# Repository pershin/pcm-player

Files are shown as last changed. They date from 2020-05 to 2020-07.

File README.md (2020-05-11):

# PCM Player

Pulse-width modulation (PWM) audio player on ATmega328P-PU

## Requirements

### SD card

SDHC 2-32GB must be formatted to FAT32

### Audio files

Property          | Value
------------------|----------------------------
| Format:         | Unsigned 8-bit PCM (RAW)  |
| Sample rate:    | 44100 Hz                  |
| Channels:       | 2                         |
| File extension: | *.PCM                     |

#### Convert FLAC to PCM with FFmpeg

```bash
ffmpeg -i 'example.flac' -ar 44100 -acodec pcm_u8 -f u8 -ac 2 'EXAMPLE.PCM'
```

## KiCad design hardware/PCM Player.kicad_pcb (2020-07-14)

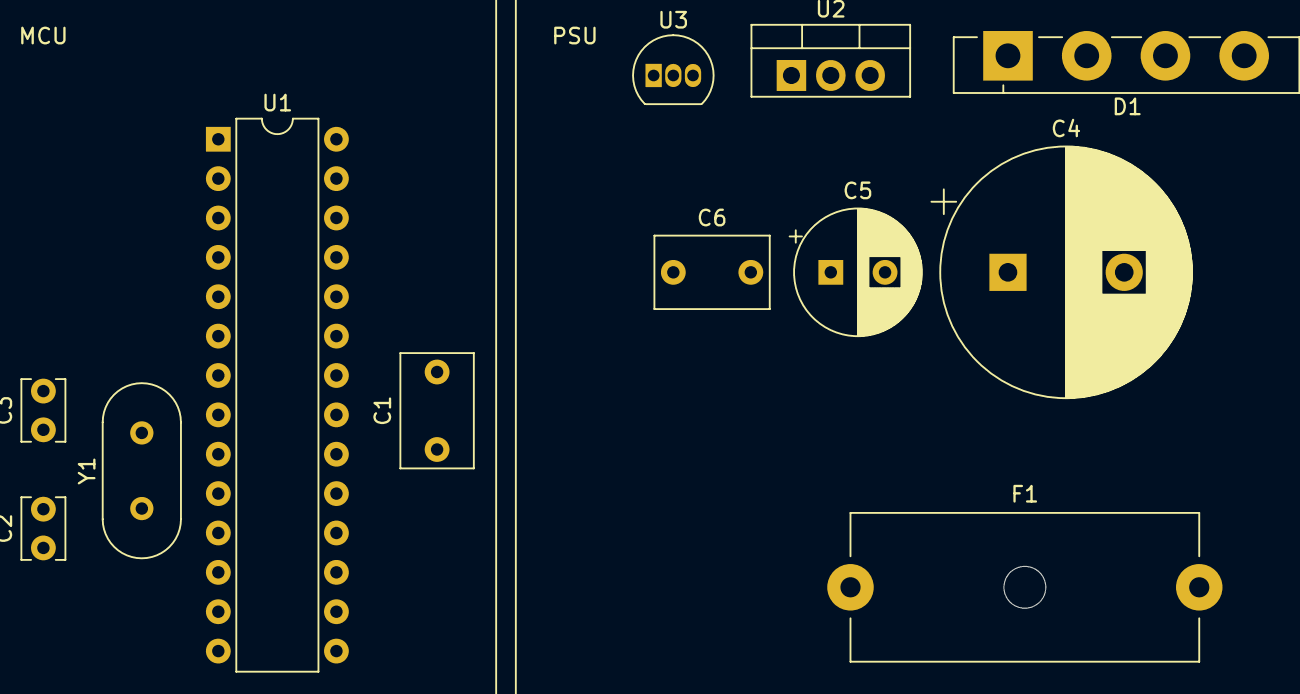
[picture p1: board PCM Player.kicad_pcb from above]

Board: 2 copper layers, 16 parts (0 on the bottom side), 6 nets, no tracks yet.

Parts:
C1, C6: 1u; C_Rect_L7.2mm_W4.5mm_P5.00mm_FKS2_FKP2_MKS2_MKP2
C2, C3: 22p; C_Disc_D3.8mm_W2.6mm_P2.50mm
C4: 4700u; CP_Radial_D16.0mm_P7.50mm
C5: 100u; CP_Radial_D8.0mm_P3.50mm
D1: GBU808; Diode_Bridge_Vishay_GBU
F1: 250V 4A; Fuseholder_Cylinder-5x20mm_Schurter_0031_8201_Horizontal_Op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
H1, H2, H3, H4: MountingHole; MountingHole_3.2mm_M3
U1: ATmega328P-PU; DIP-28_W7.62mm
U2: LM1085-5.0; TO-220-3_Vertical
U3: LP2950-3.3_TO92; TO-92_Inline
Y1: 16MHz; Crystal_HC49-U_Vertical

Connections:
+3V3: C6.1, U3.1
+5V: C1.1, C5.1, U1.7, U1.20, U2.2, U3.3
GND: C1.2, C2.2, C3.2, C4.2, C5.2, C6.2, D1.4, U1.8, U1.22, U2.1, U3.2
unnamed: C2.1, U1.10, Y1.1
unnamed: C3.1, U1.9, Y1.2
VCC: C4.1, D1.1, U2.3

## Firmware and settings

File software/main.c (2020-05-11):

/*
 * File:   main.c
 * Author: Sergey Pershin <sergey.pershin at hotmail.com>
 *
 * Created on May 7, 2020, 7:14 PM
 */

#include <avr/io.h>
#include <avr/interrupt.h>
#include <stdint.h>
#include "player.h"
#include "pins.h"
#include "spi.h"
#include "sd.h"
#include "fat32.h"
#include "display.h"

extern uint8_t command_id;
uint16_t current_track;
volatile uint8_t minutes;
volatile uint8_t seconds;
volatile uint16_t buffer_position;
volatile uint16_t position_count;
uint8_t buffer[BUFFER_SIZE];
uint8_t buffer_n;

ISR(TIMER1_COMPA_vect) {
  OCR2B = buffer[buffer_position++]; /* Left channel */
  OCR0B = buffer[buffer_position++]; /* Right channel */

  if (BUFFER_SIZE == buffer_position) {
    buffer_position = 0;
  }

  position_count--;

  if (0 == position_count) {
    position_count = SAMPLE_RATE;
    seconds++;

    /* Fix BCD */
    if (9 < (seconds & ~0b11110000)) {
      seconds += 0b00000110;
    }
  }

  if (0x60 == seconds) { /* 60 */
    seconds = 0;
    minutes++;

    /* Fix BCD */
    if (9 < (minutes & ~0b11110000)) {
      minutes += 0b00000110;
    }
  }
}

void next(void);

void read_to_buffer(void) {
  int16_t offset, read_result;

  if (0 == TIMSK1) {
    return;
  }

  if (0 == buffer_n) {
    if (BUFFER_CHUNK > buffer_position) {
      return;
    }

    buffer_n = 1;
    offset = 0;
  } else {
    if (BUFFER_CHUNK <= buffer_position) {
      return;
    }

    buffer_n = 0;
    offset = BUFFER_CHUNK;
  }

  read_result = file_read(&buffer[offset]);

  if (-1 == read_result) {
    next();
    return;
  }

  if (BUFFER_CHUNK > read_result) {
    next();
  }
}

void play(void) {
  /* Start timer (TIMER1_COMPA_vect) */
  TIMSK1 = (1 << OCIE1A);
}

void stop(void) {
  TIMSK1 = 0;
  buffer_position = 0;
  buffer_n = 0;
  seconds = 0;
  minutes = 0;
  position_count = SAMPLE_RATE;
}

void open(uint16_t track) {
  if (file_open(track)) {
    next();
    return;
  }

  file_read(buffer);
  file_read(&buffer[BUFFER_CHUNK]);
}

void next(void) {
  stop();
  current_track++;
  open(current_track);
  play();
}

void prev(void) {
  stop();
  current_track--;
  open(current_track);
  play();
}

/* Initialization */
void init() {
  /* Set MOSI, SCK and SS output */
  DDRB |= (1 << PIN_DISPLAY_ENABLE) |
          (1 << PIN_DISPLAY_LATCH) |
          (1 << PIN_SPI_SS) |
          (1 << PIN_SPI_MOSI) |
          (1 << PIN_SPI_SCK);

  /* Set PIN_LOUT and PIN_ROUT as output (PWM) */
  DDRD |= (1 << PIN_LOUT) | (1 << PIN_ROUT);

  /* PWM (OCR0B, OCR2B) */
  TCCR0A = (1 << COM0B1) | (1 << WGM01) | (1 << WGM00);
  TCCR2A = TCCR0A;

  /* TIMER1_COMPA_vect */
  TCCR1B = (1 << WGM12) | (1 << CS10);

  /* 44.1 kHz */
  OCR1A = F_CPU / SAMPLE_RATE;

  /* Start PWM */
  TCCR0B = (1 << CS00); /* no prescaling */
  TCCR2B = TCCR0B;

  PORTD |= (1 << PIN_INT0) | (1 << PIN_NEXT) | (1 << PIN_PREV);

  EICRA = (1 << ISC01);
  EIMSK = (1 << INT0);

  /* Enable interrupts */
  __asm("sei");

  spi_init();
  sd_init();
  fat32_mount();
}

int main(void) {
  uint16_t old_track;
  uint8_t old_seconds, show_track;

  init();

  command_id = 0;
  old_track = 0;
  old_seconds = 0;
  show_track = 3;

  stop();
  current_track = 1;
  open(current_track);
  play();

  for (;;) {
    if (old_track != current_track) {
      old_track = current_track;
      show_track = 4;
      display_track(current_track);
    }

    if (0 != show_track && old_seconds != seconds && 0 != seconds) {
      show_track--;
    }

    if (0 == show_track && old_seconds != seconds) {
      old_seconds = seconds;
      display_position(minutes, seconds);
    }

    read_to_buffer();

    if (0 != command_id) {
      switch (command_id) {
        case COMMAND_NEXT:
          next();
          break;
        case COMMAND_PREV:
          prev();
          break;
      }

      command_id = 0;
    }
  }

  return 0;
}

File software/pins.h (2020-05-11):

/*
 * File:   pins.h
 * Author: Sergey Pershin <sergey.pershin at hotmail.com>
 *
 * Created on May 8, 2020, 7:20 PM
 */

#ifndef PINS_H
#define PINS_H

#define PIN_DISPLAY_ENABLE PB0 /* Enable (seven-segment display) */
#define PIN_DISPLAY_LATCH  PB1 /* Latch (seven-segment display) */
#define PIN_SPI_SS         PB2 /* CS (Slave Select) */
#define PIN_SPI_MOSI       PB3 /* DI (Master Out Slave In) */
#define PIN_SPI_MISO       PB4 /* D0 (Master In Slave Out) */
#define PIN_SPI_SCK        PB5 /* SCK (Serial Clock) */
#define PIN_INT0           PD2
#define PIN_LOUT           PD3 /* Left Channel */
#define PIN_ROUT           PD5 /* Right Channel */
#define PIN_NEXT           PD6
#define PIN_PREV           PD7

#endif /* PINS_H */

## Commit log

2020-05-22 Added PSU
    [MCU.sch, PCM Player.sch, PSU.sch]
2020-05-22 Updated PCB
    [MCU.sch, PCM Player.kicad_pcb, PCM Player.sch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]
2020-07-14 Added amplifier schematic
    [Amp.sch, MCU.sch, PCM Player.kicad_pcb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]
